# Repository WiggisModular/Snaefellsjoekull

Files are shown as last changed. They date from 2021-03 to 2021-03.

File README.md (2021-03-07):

Snæfellsjökull

** Prodution files out of date, pots go the wrong way round. **

A simple modular eurorack stereo mixer.

## Modules

### panMonoCannel

* Panning mono channel

### MainNoFx

* A main out, 2 separate pots for out Volume.
* No FX send and return 

## Production Files and Documentation

See release tab

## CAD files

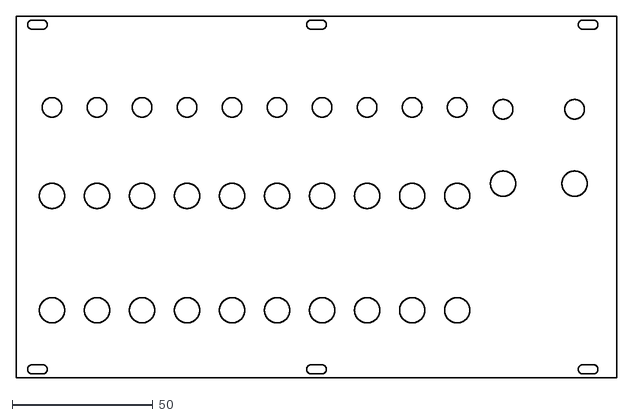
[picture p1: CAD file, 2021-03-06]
panel/Panel.dxf
213.4 x 128.5

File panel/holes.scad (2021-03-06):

module hole(diameter){
    cylinder(h=thickness*3, d=diameter,center=true,$fn=180);
}

module slit(length, width){
        cube([length-width,width,thickness*3],center=true);
        translate([length/2-width/2,0, 0]) {
            cylinder(d=width,h=thickness*3,center=true,$fn=180);
        }
        translate([-length/2+width/2,0, 0]) {
            cylinder(d=width,h=thickness*3,center=true,$fn=180);
        }
        
}

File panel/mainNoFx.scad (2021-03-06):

module mainNoFx() {
    translate([10, 69, 0]) {
        hole(potHolesize);
    }
    translate([10,69+26.42,0]){
        hole(connHolesize);
    }
    translate([10+25.4 , 69, 0]) {
        hole(potHolesize);
    }
    translate([10+25.4,69+26.42,0]){
        hole(connHolesize);
    }
}

module mainNoFxs(){
    if (mnfNumber > 0 ) {
        for (i=[0:mnfNumber-1]) {
            translate([i*mnfWidth,0, 0]) {
                mainNoFx();
            }
        }
    }
}

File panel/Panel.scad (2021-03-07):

include <panMonoChannel.scad>
include <mainNoFx.scad>
include <holes.scad>

/* [panMonoChannel] */
pmcWidth = 16; // [44:1:54]
pmcNumber = 10;

/* [mainNoFx] */
mnfWidth = 44; // [44:1:54]
mnfNumber = 1;
mnfPos = "R"; // [R:Right, L:Left]

/* [General] */
sizeInHP=42;
potHolesize = 7;
connHolesize = 6;
thickness = 2;
export = 0; // [0:False, 1:True]

/* [Here be dragons] */
panelHeight =128.5;
hp=5.08;


panelWidth = sizeInHP*hp;
spacing = (panelWidth-(pmcWidth*pmcNumber+mnfWidth*mnfNumber))/2;

if ( export == 1) {
   projection() panel();
} else {
    panel();
}

module panel(){
    echo(str("Panel width: ", panelWidth));
    difference() {
        cube(size=[panelWidth, panelHeight, thickness], center=false);
        // panMonoChannels
        if (mnfPos == "R") {
            translate([spacing,0, 0]) {
                panMonoChannels();
            }
            translate([pmcWidth*(pmcNumber)+3,0,0]){
                mainNoFxs();
            }
        } else {
            translate([spacing + mnfWidth*(mnfNumber), 0, 0]) {
                panMonoChannels();
            } 
            mainNoFxs();  
        }
        translate([7.5,3 , 0]) {
            slit(7,3.3);
        }
        translate([7.5,panelHeight-3, 0]) {
            slit(7,3.3);
        }
        translate([(sizeInHP-2)*hp,3,0]) {
            slit(7,3.3);
        }
        translate([(sizeInHP-2)*hp,panelHeight-3,0]) {
            slit(7,3.3);
        }
        translate([(sizeInHP/2)*hp,3,0]) {
            slit(7,3.3);
        }
        translate([(sizeInHP/2)*hp,panelHeight-3,0]) {
            slit(7,3.3);
        }
    }
}

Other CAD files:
panel/panMonoChannel.scad

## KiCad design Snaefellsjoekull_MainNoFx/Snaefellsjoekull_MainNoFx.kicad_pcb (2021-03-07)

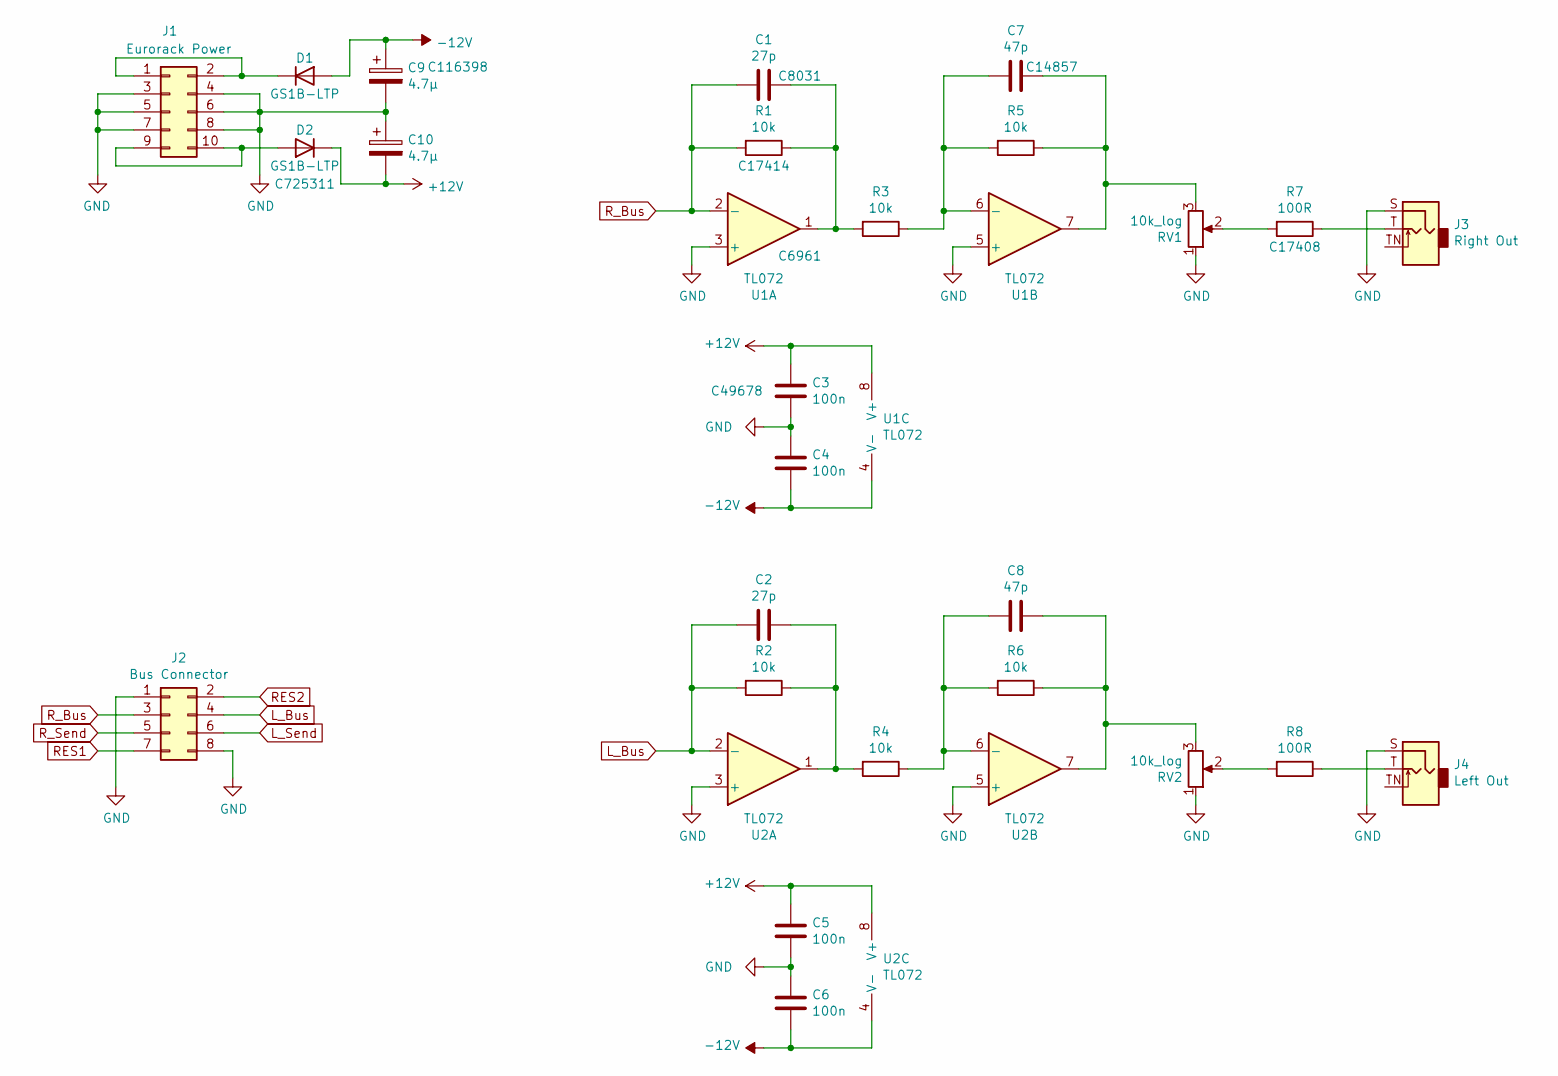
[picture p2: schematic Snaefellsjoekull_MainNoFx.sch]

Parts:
C1, C2: 27p; C_0805_2012Metric_Pad1.18x1.45mm_HandSolder; LCSC C8031
C3, C4, C5, C6: 100n; C_0805_2012Metric_Pad1.18x1.45mm_HandSolder; LCSC C49678
C7, C8: 47p; C_0805_2012Metric_Pad1.18x1.45mm_HandSolder; LCSC C14857
C9, C10: 4.7µ; CP_Elec_4x5.8; LCSC C116398
D1, D2: GS1B-LTP; D_SMA-SMB_Universal_Handsoldering; LCSC C725311
J1: Eurorack Power; PinHeader_2x05_P2.54mm_Vertical
J2: Bus Connector; PinHeader_2x04_P2.54mm_Vertical
J3: Right Out; Jack_3.5mm_QingPu_WQP-PJ398SM_Vertical_CircularHoles
J4: Left Out; Jack_3.5mm_QingPu_WQP-PJ398SM_Vertical_CircularHoles
R1, R2, R3, R4, R5, R6: 10k; R_0805_2012Metric_Pad1.20x1.40mm_HandSolder; LCSC C17414
R7, R8: 100R; R_0805_2012Metric_Pad1.20x1.40mm_HandSolder; LCSC C17408
RV1, RV2: 10k_log; Potentiometer_Alpha_RD901F-40-00D_Single_Vertical_CircularH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
U1, U2: TL072; SOIC-8_3.9x4.9mm_P1.27mm; LCSC C6961

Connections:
+12V: C3.1, C5.1, C10.2, D2.1 (K), U1.8 (V+), U2.8 (V+)
-12V: C4.2, C6.2, C9.1, D1.2 (A), U1.4 (V-), U2.4 (V-)
GND: C3.2, C4.1, C5.2, C6.1, C9.2, C10.1, J1.3, J1.4, J1.5, J1.6, J1.7, J1.8, J2.1, J2.8, J3.S, J4.S, RV1.1, RV2.1, U1.3 (+), U1.5 (+), U2.3 (+), U2.5 (+)
L_Bus: C2.1, J2.4, R2.2, U2.2 (-)
L_Send: J2.6
unnamed: C1.2, R1.1, R3.2, U1.1
unnamed: C2.2, R2.1, R4.2, U2.1
unnamed: C7.1, R3.1, R5.2, U1.6 (-)
unnamed: C7.2, R5.1, RV1.3, U1.7
unnamed: C8.1, R4.1, R6.2, U2.6 (-)
unnamed: C8.2, R6.1, RV2.3, U2.7
unnamed: D1.1 (K), J1.1, J1.2
unnamed: D2.2 (A), J1.9, J1.10
unnamed: J3.T, R7.1
unnamed: J4.T, R8.1
unnamed: R7.2, RV1.2
unnamed: R8.2, RV2.2
RES1: J2.7
RES2: J2.2
R_Bus: C1.1, J2.3, R1.2, U1.2 (-)
R_Send: J2.5

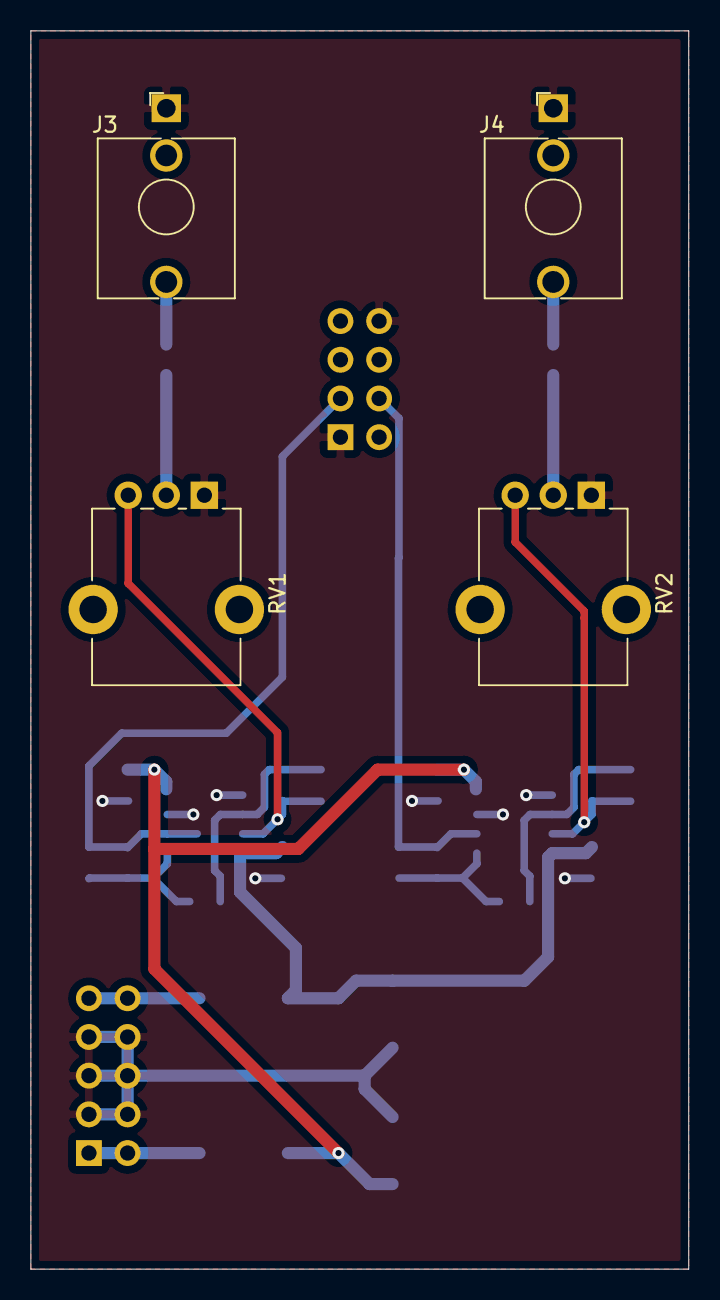
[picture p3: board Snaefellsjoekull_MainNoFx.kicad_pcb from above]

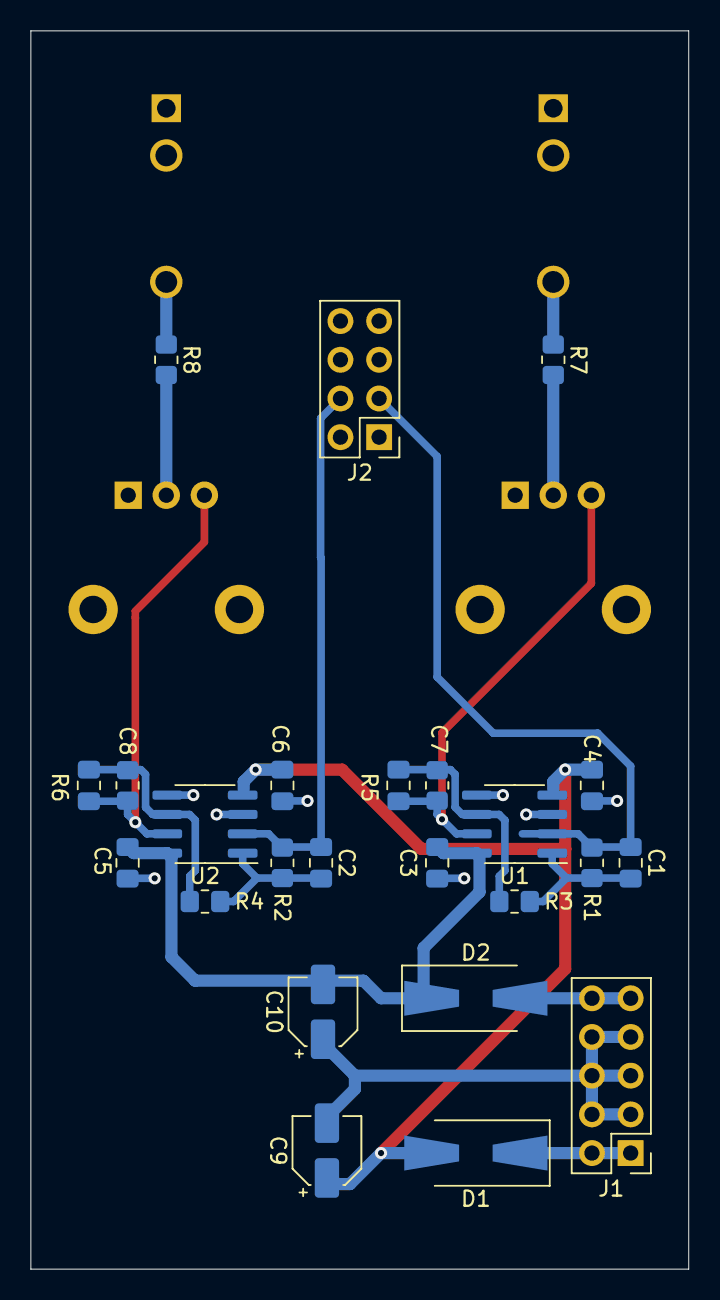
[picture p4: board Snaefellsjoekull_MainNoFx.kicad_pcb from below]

Board: 2 copper layers, 43.2 x 81.3 mm, 28 parts (24 on the bottom side), 17 nets.

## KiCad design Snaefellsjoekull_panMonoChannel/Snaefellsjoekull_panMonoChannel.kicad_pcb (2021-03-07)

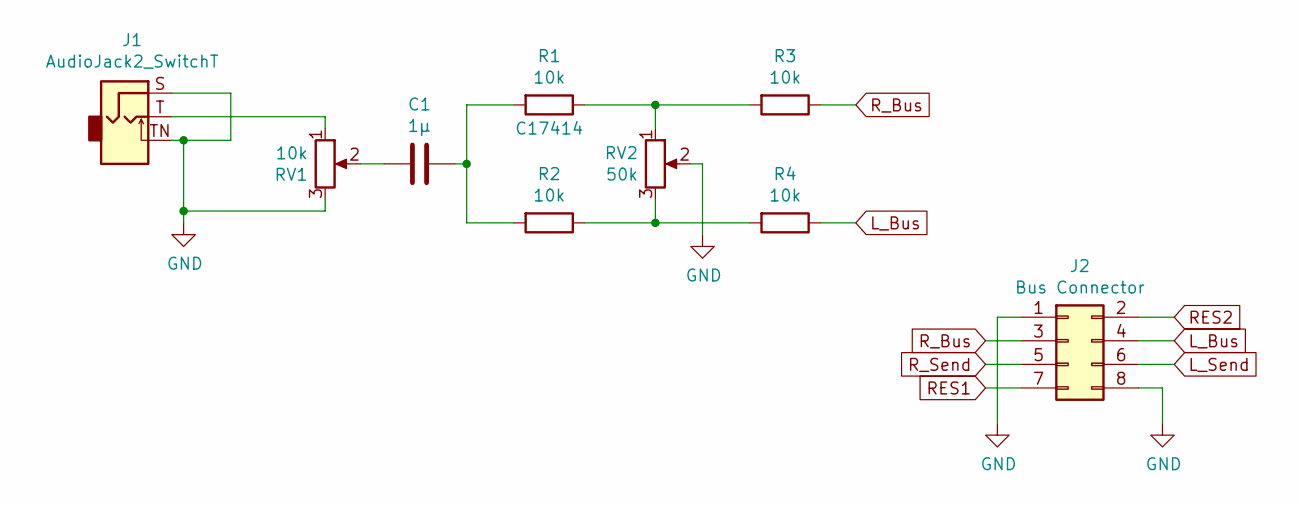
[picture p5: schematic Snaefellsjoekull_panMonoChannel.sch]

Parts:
C1: 1µ; C_0805_2012Metric_Pad1.18x1.45mm_HandSolder; LCSC C28323
J1: AudioJack2_SwitchT; Jack_3.5mm_QingPu_WQP-PJ398SM_Vertical_CircularHoles
J2: Bus Connector; PinHeader_2x04_P2.54mm_Vertical
R1, R2, R3, R4: 10k; R_1206_3216Metric_Pad1.30x1.75mm_HandSolder; LCSC C17414
RV1: 10k; Potentiometer_Bourns_PTV09A-1_Single_Vertical
RV2: 50k; Potentiometer_Bourns_PTV09A-1_Single_Vertical

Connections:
GND: J1.S, J1.TN, J2.1, J2.8, RV1.3, RV2.2
L_Bus: J2.4, R4.1
L_Send: J2.6
unnamed: C1.1, R1.2, R2.2
unnamed: C1.2, RV1.2
unnamed: J1.T, RV1.1
unnamed: R1.1, R3.2, RV2.1
unnamed: R2.1, R4.2, RV2.3
RES1: J2.7
RES2: J2.2
R_Bus: J2.3, R3.1
R_Send: J2.5

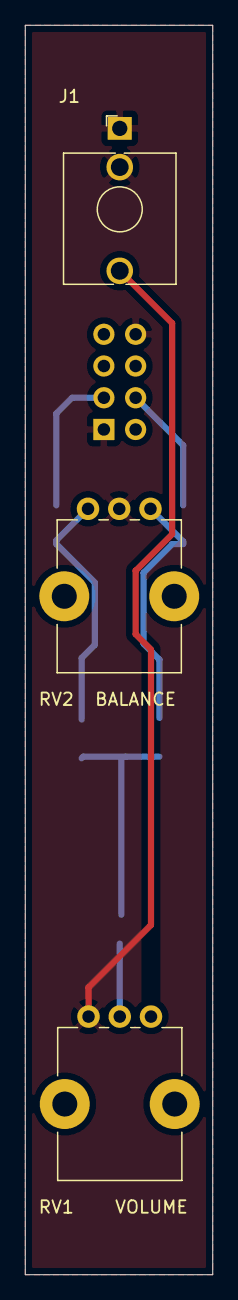
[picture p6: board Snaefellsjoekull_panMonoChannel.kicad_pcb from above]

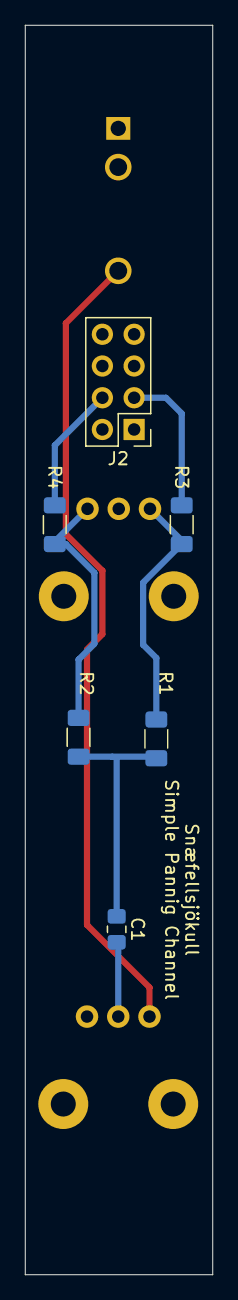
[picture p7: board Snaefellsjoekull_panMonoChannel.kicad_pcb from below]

Board: 2 copper layers, 15.0 x 100.0 mm, 9 parts (6 on the bottom side), 8 nets.

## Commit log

2021-02-08 Inital data commit
    [Snaefellsjoekull_MainNoFx.kicad_pcb, Snaefellsjoekull_MainNoFx.sch, Snaefellsjoekull_panMonoChannel.kicad_pcb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]
2021-03-05 Panel generator added
    [Panel.scad, Snaefellsjoekull_panMonoChannel.kicad_pcb]
2021-03-05 main pos inplemented
    [Panel.scad]
2021-03-05 added dimensions
    [Snaefellsjoekull_MainNoFx.kicad_pcb]
2021-03-06 modularized openscad
    [Panel.scad, holes.scad, mainNoFx.scad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]
2021-03-06 generated dxf
    [Panel.dxf]
2021-03-06 PCB updated
    [Snaefellsjoekull_MainNoFx.kicad_pcb]
2021-03-07 fixed standard values
    [Panel.scad]
2021-03-07 Potentiometer fixed
    [Snaefellsjoekull_MainNoFx.kicad_pcb, Snaefellsjoekull_MainNoFx.sch, Snaefellsjoekull_panMonoChannel.kicad_pcb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]
